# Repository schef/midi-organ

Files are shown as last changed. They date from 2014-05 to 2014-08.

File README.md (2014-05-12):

midi-organ
==========

Modifying and rebuilding electronics for an old electronic organ using GNU/Linux, Arduino, GEDA suite...

LICENSE:
Released under the Creative Commons Attribution share-Alike 3.0 License
http://creativecommons.org/licenses/by-sa/3.0/

CREDITS:
1)Symbols and footprints:
		-gedasymbols (www.gedasymbols.org)	
		-74HC165-1.sym symbol from https://github.com/thefekete/etc-geda/tree/master/lib/symbols/7400
2)Jordan, (http://dduino.blogspot.com/2012/04/arduino-74hc165-psio-shift-regsiter.html) - providing guide for Arduino 74HC165 PSIO Shift Regsiters

REFERENCES:
http://dduino.blogspot.com/2012/04/arduino-74hc165-psio-shift-regsiter.html
http://www.gedasymbols.org

Stjepan & Benjamin Horvat
http://horvat-elektronika.hr

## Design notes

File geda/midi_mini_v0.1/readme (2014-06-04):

commands:

refdes_renum arduino_standalone_extended.sch 74hc165_x4.sch 74hc164.sch 74hc595_x6.sch midi_connector.sch expresion_pedal_1.sch expresion_pedal_2.sch expresion_pedal_3.sch analog_generic_1.sch analog_generic_2.sch analog_generic_3.sch

gsch2pcb projekt

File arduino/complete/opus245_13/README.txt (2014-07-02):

ova verzija je napravljena za male skrablove orgulje sto znaci:
samo 2x595 (4 manje)
dodan relay za paljenje orgulja na pin D7
dodan potenciometar na A0
slozen da se boot sekvenca gasi na ulazni midi ton ch5
pojacalo se pali i gasi na ch5,127

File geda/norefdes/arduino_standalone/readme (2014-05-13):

REFERENCE:
http://www.arduino.cc/en/Main/StandaloneAssembly
http://www.instructables.com/id/Adding-ICSP-header-to-your-ArduinoAVR-board/#step0
http://www.open-electronics.org/arduino-isp-in-system-programming-and-stand-alone-circuits/

PART_LIST:
http://arduino.cc/en/Main/StandalonePartList

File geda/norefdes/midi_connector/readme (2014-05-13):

REFERENCES:
http://arduino.cc/en/Tutorial/Midi?from=Tutorial.MIDI

PART_LIST:
resistor 220 ohm

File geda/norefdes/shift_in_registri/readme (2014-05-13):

REFERENCES:
 http://dduino.blogspot.com/2012/04/arduino-74hc165-psio-shift-regsiter.html

PART_LIST:
resistor 10 Kohm

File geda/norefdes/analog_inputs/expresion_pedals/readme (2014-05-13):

REFERENCES: 
http://arduino.cc/en/Tutorial/AnalogInput
http://lizarum.com/assignments/physical_computing/2011/arduino_102.html

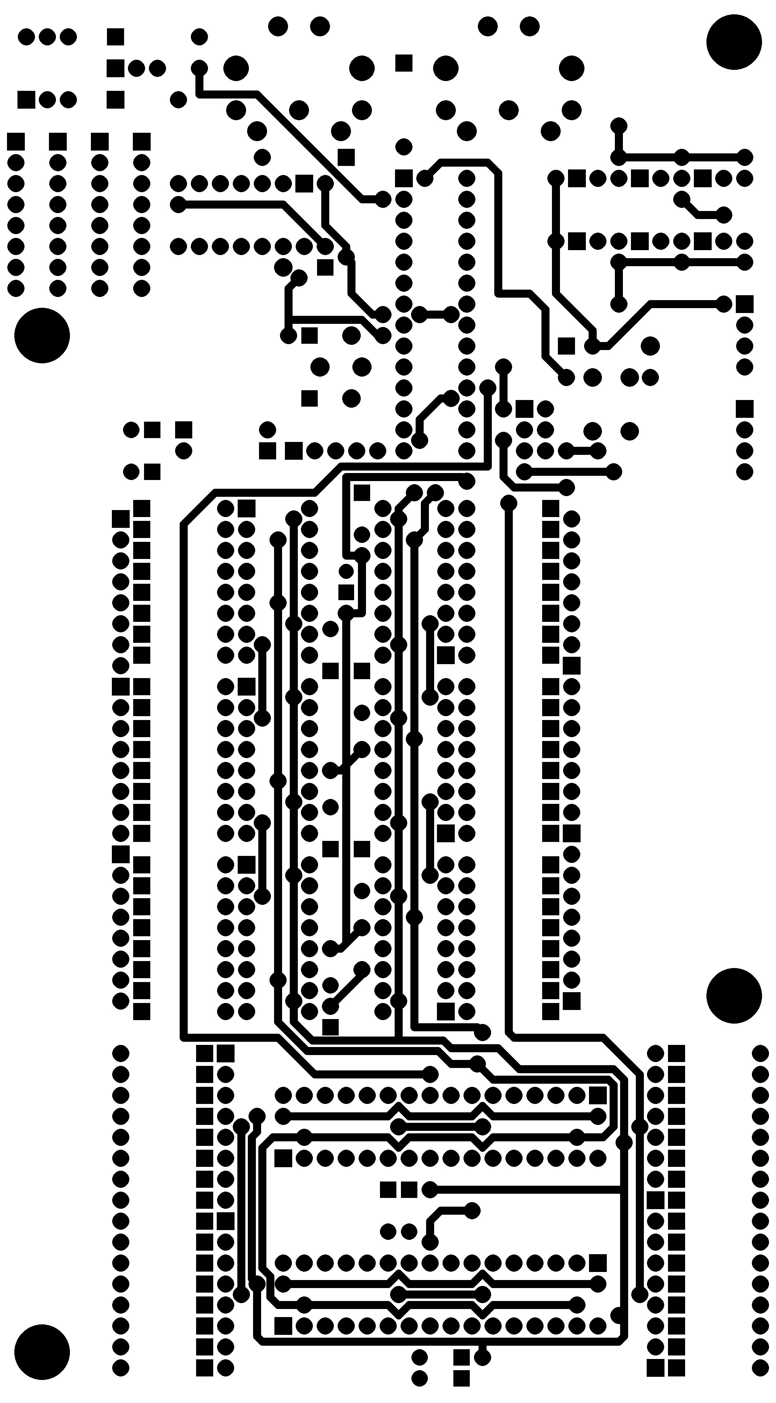
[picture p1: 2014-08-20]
geda/midi_mini_v0.1/midi_organ_v0.2.gcode.top.png

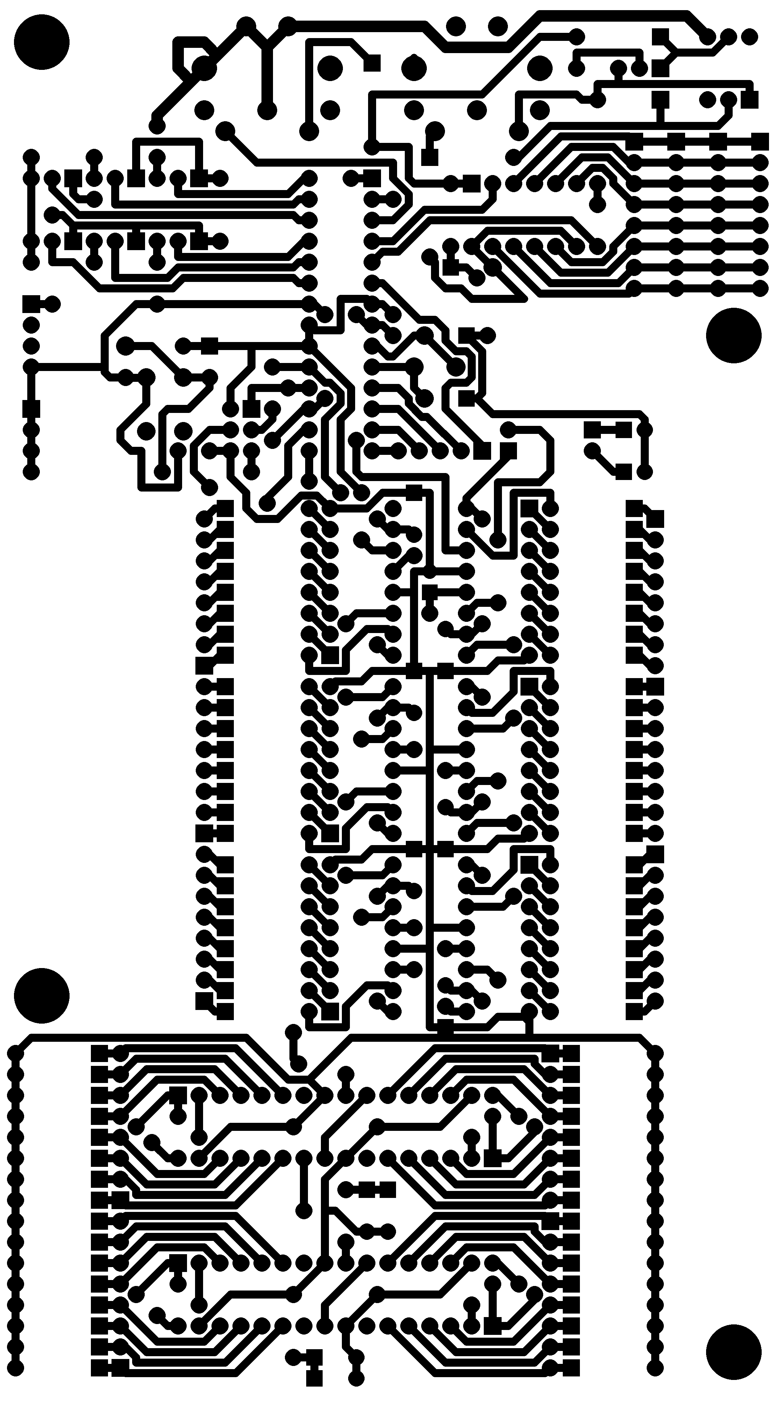
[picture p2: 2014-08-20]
geda/midi_mini_v0.1/midi_organ_v0.2.gcode.bottom.png

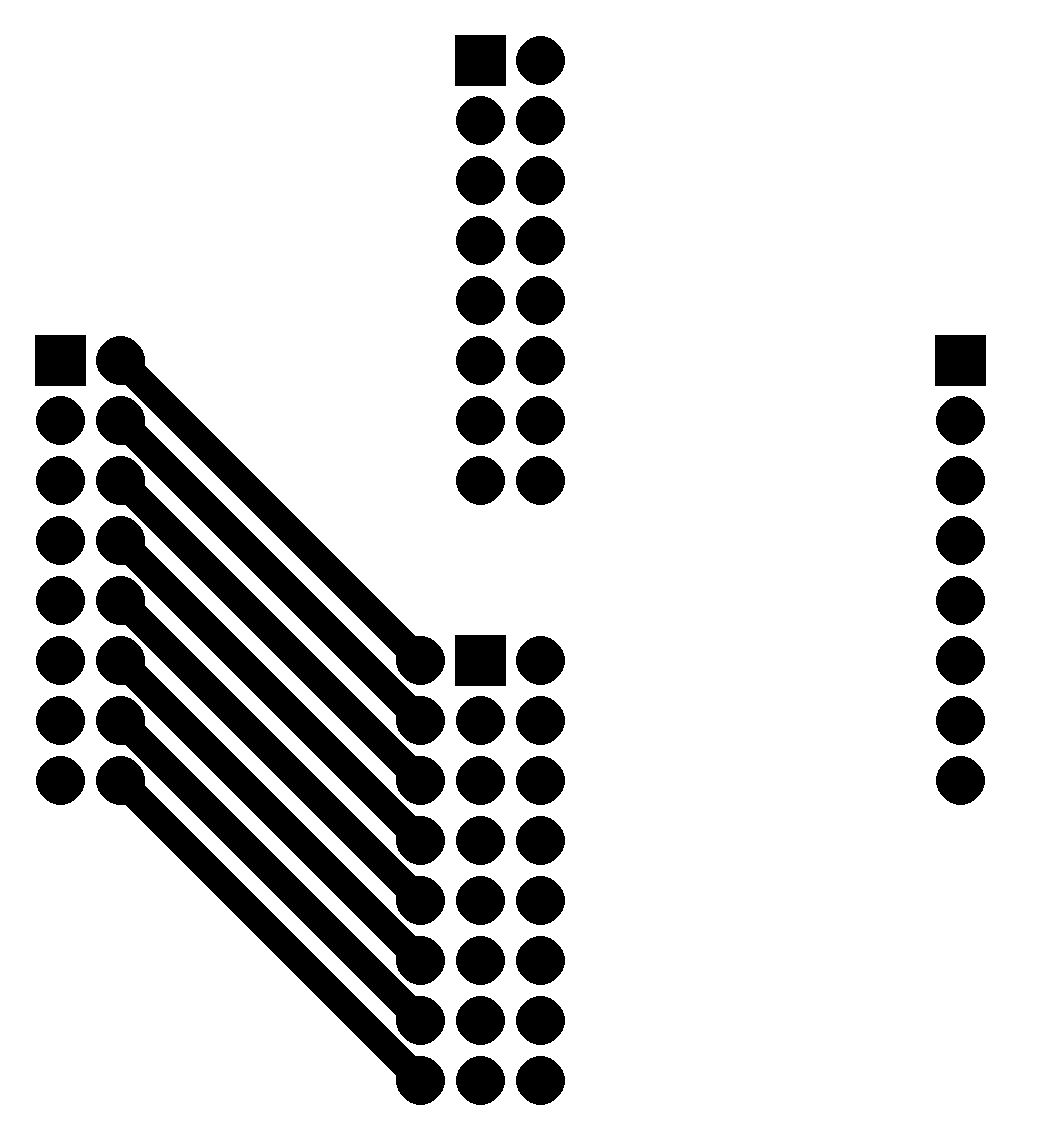
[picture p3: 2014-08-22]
geda/norefdes/fatar_converter/fatar_converter.gcode.top.png

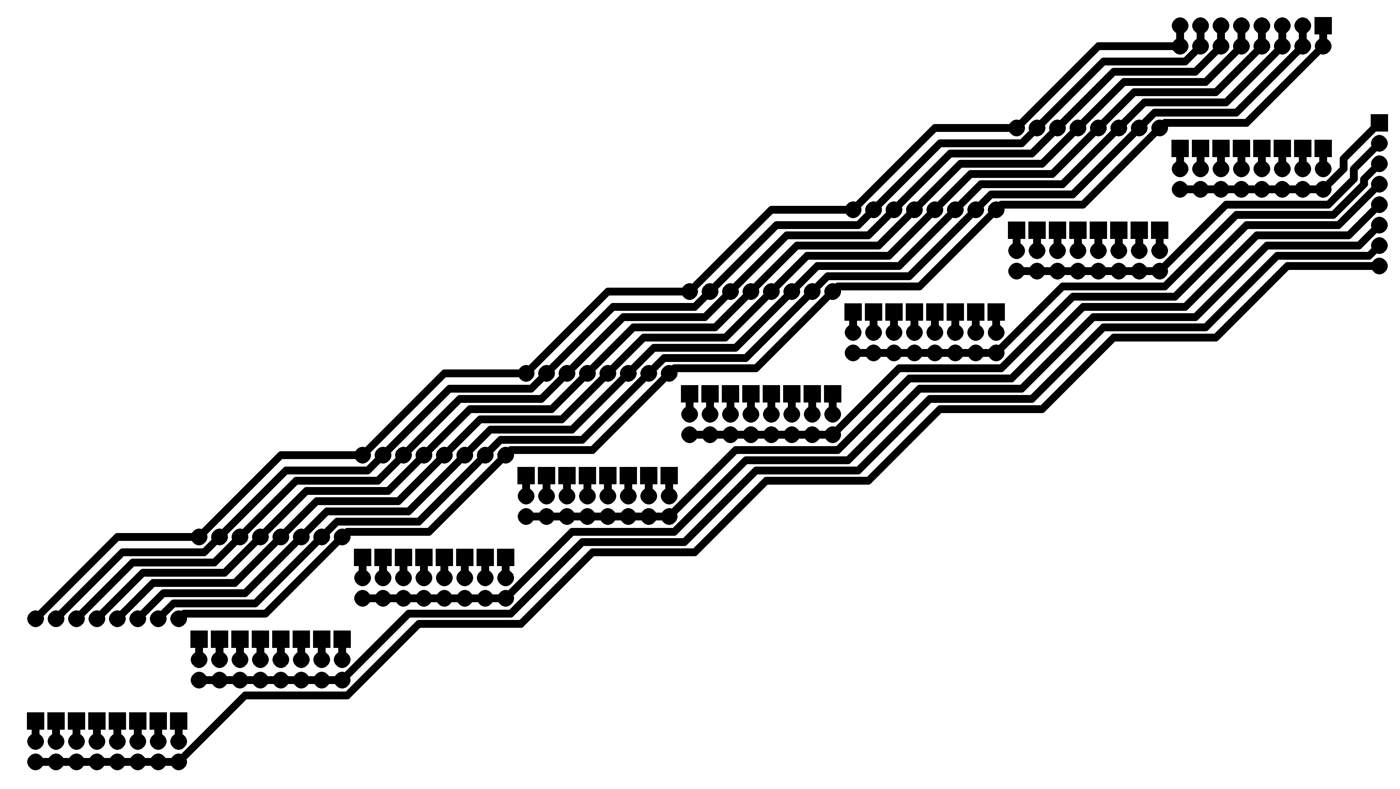
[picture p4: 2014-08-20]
geda/matrica/matrica.gcode.bottom.png

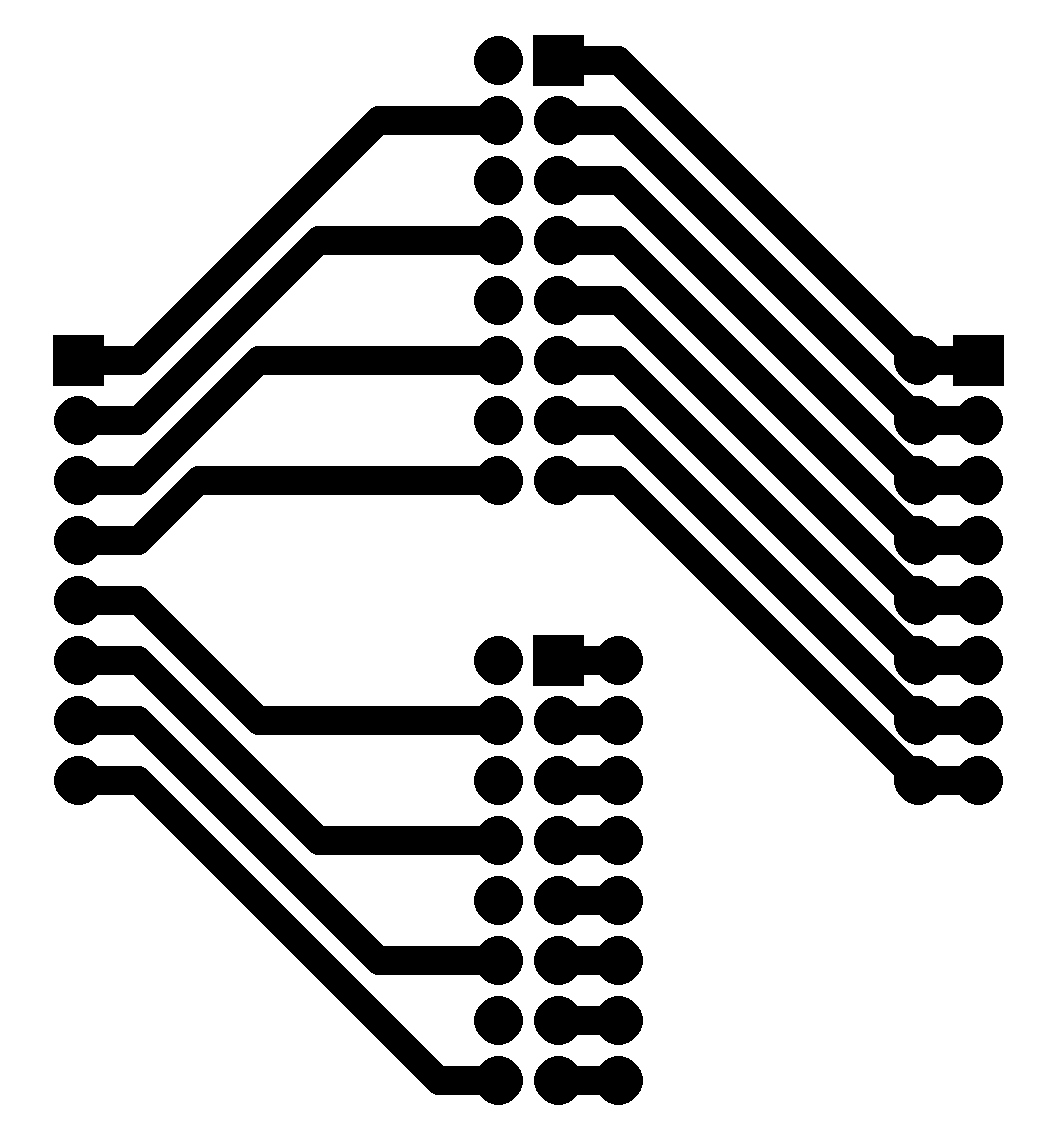
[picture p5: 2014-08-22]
geda/norefdes/fatar_converter/fatar_converter.gcode.bottom.png

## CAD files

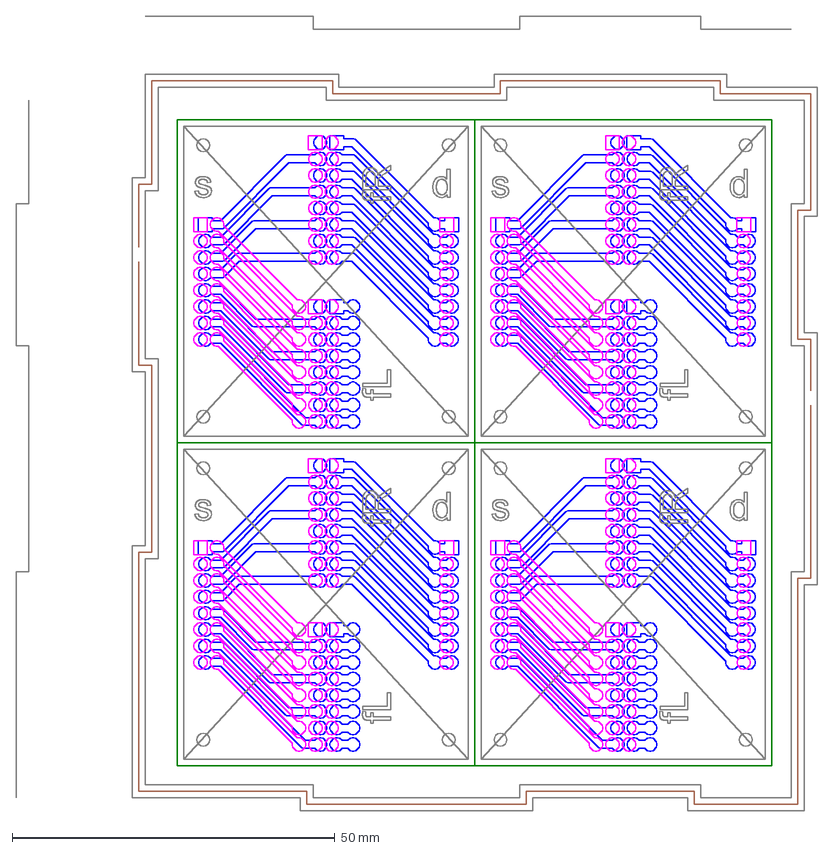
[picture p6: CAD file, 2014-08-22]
geda/norefdes/fatar_converter/fatar_converter.gcode.complete.dxf
124.0 x 123.0 mm

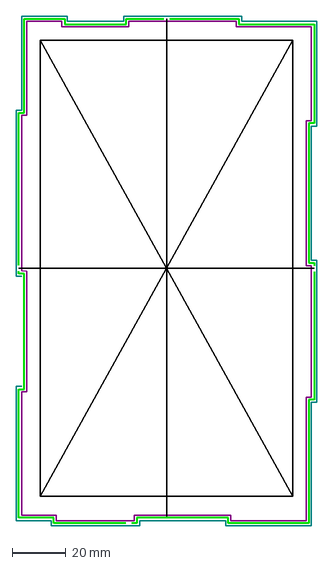
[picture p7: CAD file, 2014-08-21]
geda/midi_mini_v0.1/midi_organ_v0.2.gcode.complete.dxf
112.0 x 190.0 mm

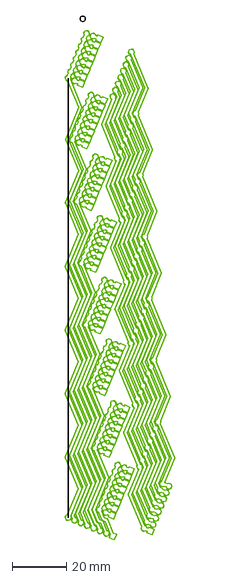
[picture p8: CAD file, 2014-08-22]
geda/matrica/matrica_deblje10mill.gcode-complete.dxf
40.2 x 192.4 mm

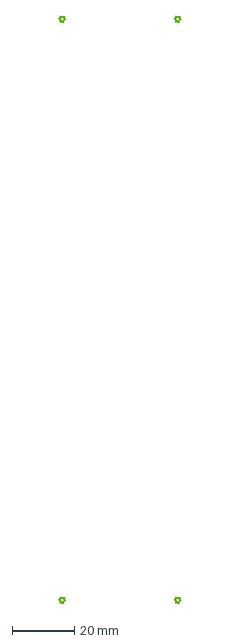
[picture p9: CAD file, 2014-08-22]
geda/matrica/matrica.gcode.complete[drill-3.25]-1mm.dxf
39.2 x 188.1 mm

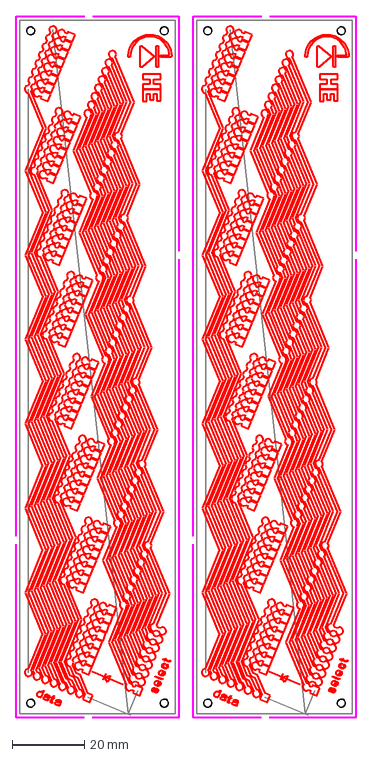
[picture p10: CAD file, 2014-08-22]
geda/matrica/matrica.gcode.complete-double.dxf
94.0 x 194.0 mm

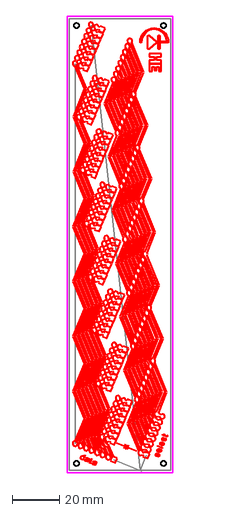
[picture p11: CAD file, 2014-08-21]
geda/matrica/matrica.gcode.complete.dxf
45.0 x 194.0 mm

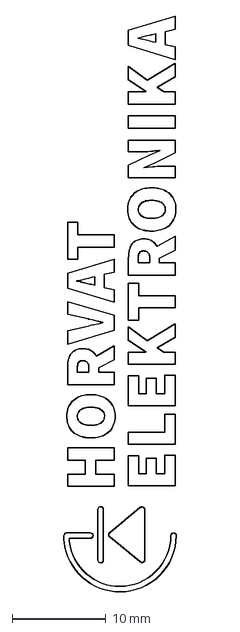
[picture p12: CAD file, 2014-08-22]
geda/midi_mini_v0.1/logo.dxf
12.0 x 61.4 mm

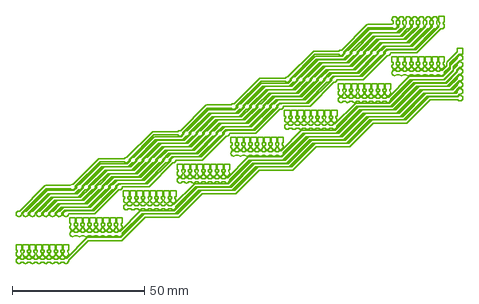
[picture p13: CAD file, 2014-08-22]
geda/matrica/matrica_deblje10mill.gcode.bottom.dxf
169.2 x 93.6 mm

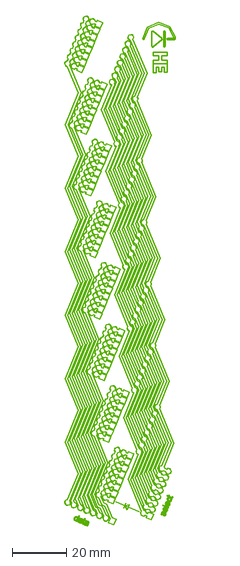
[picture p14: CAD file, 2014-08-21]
geda/matrica/matrica.gcode.bottom-06mm.dxf
40.6 x 187.5 mm

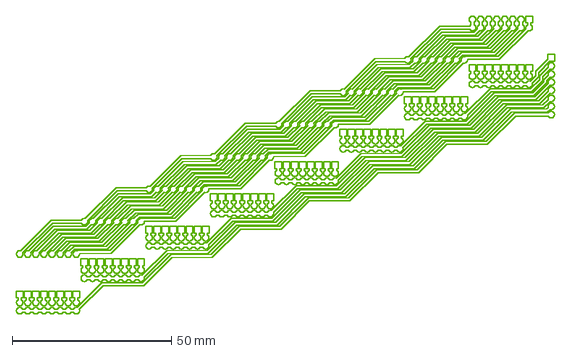
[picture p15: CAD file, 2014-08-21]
geda/matrica/matrica.gcode.bottom.dxf
169.2 x 93.6 mm

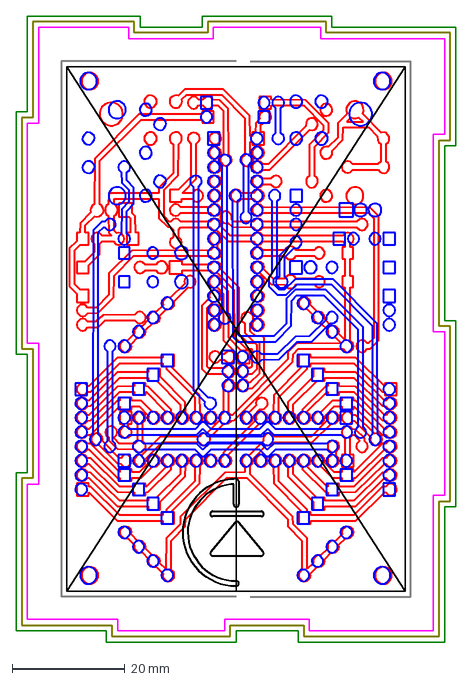
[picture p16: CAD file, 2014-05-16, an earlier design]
geda/complete_v0.1/complete.dxf
78.0 x 111.0 mm

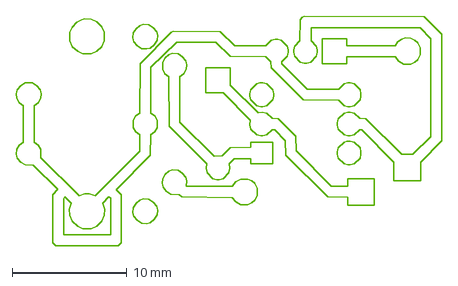
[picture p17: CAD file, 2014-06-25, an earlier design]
geda/complete_v0.2/midi_out_connector.gcode.bottom.dxf
37.1 x 20.0 mm

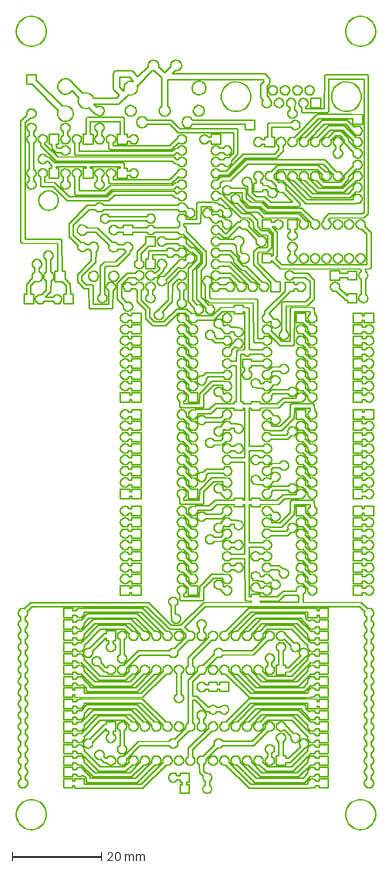
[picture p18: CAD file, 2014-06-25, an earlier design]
geda/complete_v0.2/midi_organ_v0.2_mm.gcode.bottom.dxf
80.4 x 182.0 mm

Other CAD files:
geda/matrica/matrica.gcode.complete.[drill-08].dxf
geda/matrica/matrica.gcode.complete.[drill-09].dxf
geda/matrica/matrica_deblje10mill.gcode.drill.dxf
geda/matrica/matrica.gcode.drill.dxf
geda/complete_v0.2/midi_out_connector.gcode.drill.dxf
geda/complete_v0.2/matrica_8x8.gcode.bottom.dxf
geda/complete_v0.2/matrica_8x8.gcode.bottom_multi.dxf
geda/complete_v0.2/midi_organ_v0.2.gcode.bottom.dxf
geda/complete_v0.2/midi_organ_v0.2.gcode.top.dxf
geda/complete_v0.2/midi_organ_v0.2_mm.gcode.all.[rub].dxf
geda/complete_v0.2/midi_organ_v0.2_mm.gcode.all.dxf
geda/complete_v0.2/midi_organ_v0.2_mm.gcode.top.dxf
geda/complete_v0.2/midi_out_connector.gcode.all.dxf

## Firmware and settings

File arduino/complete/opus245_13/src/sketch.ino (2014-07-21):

#include <MIDI.h>
//definiranje nozista

//164 pins
//int clearPin = 2; // enablepin
int data164Pin = 2;
int clock164Pin = 3;

//165 pins
//int inclearPin = 11; // enablepin
int data165Pin = 12;
int load165Pin = 10; // toggling this tells the 165 to read the value into its memory for reading

//595
int load595Pin = 9;
int data595Pin = 11;

//clock pin is shared between 165 and 595
int clockPin = 13;

byte commandByte;
byte noteByte;
byte velocityByte;

//int potPin = 0;
//int potVal = 0;
//int potOldVal = 0;
//int cc = 0;

int relay = 7;

int boot = 0;
int sekvencaOne[24] = {	B00000001, //24
			B00000010,
			B00000100,
			B00001000,
			B00010000,
			B00100000,
			B01000000,
			B10000000,
			B00000000,
			B00000000,
			B00000000,
			B00000000,
			B00000000,
			B00000000,
			B00000000,
			B00000000,
			B00000000,
			B10000000,
			B01000000,
			B00100000,
			B00010000,
			B00001000,
			B00000100,
			B00000010,
};

int sekvencaTwo[24] = {	B00000000, //24
			B00000000,
			B00000000,
			B00000000,
			B00000000,
			B00000000,
			B00000000,
			B00000000,
			B00000001,
			B00000010,
			B00000100,
			B00001000,
			B00010000,
			B00001000,
			B00000100,
		B00000010,
			B00000001,
			B00000000,
			B00000000,
			B00000000,
			B00000000,
			B00000000,
			B00000000,
			B00000000,
};
//inicializacija programa
void bootSequence(){
	do{
	//if(boot == 24)
	//  boot = 0;
  digitalWrite(load595Pin, LOW);
  //shiftOut(data595Pin, clockPin, MSBFIRST, sekvencaTwo[boot]);
  //shiftOut(data595Pin, clockPin, MSBFIRST, sekvencaOne[boot]);
  shiftOut(data595Pin, clockPin, MSBFIRST, boot);
  shiftOut(data595Pin, clockPin, MSBFIRST, boot);
  digitalWrite(load595Pin, HIGH);
  delay(100);
	if(MIDI.read()){
	//if (boot == 20){
    		//MIDI.setHandleNoteOn(noteon);
    		//MIDI.setHandleNoteOff(noteoff);
		break;
	}
boot++;
}
while(1);
  digitalWrite(load595Pin, LOW);
  shiftOut(data595Pin, clockPin, MSBFIRST, 0);
  shiftOut(data595Pin, clockPin, MSBFIRST, 0);
  digitalWrite(load595Pin, HIGH);
}

void setup() {

	//start serial
	//Serial.begin(9600);

	//164
	pinMode(data164Pin, OUTPUT);
	pinMode(clock164Pin, OUTPUT);  

	//165
	pinMode(data165Pin, INPUT);
	pinMode(load165Pin, OUTPUT);

	//595
	pinMode(load595Pin, OUTPUT);
	pinMode(data595Pin, OUTPUT);


	//shared pin
	pinMode(clockPin, OUTPUT);
  	pinMode(relay, OUTPUT);


  MIDI.begin(5);          // Launch MIDI and listen to channel 4
  //MIDI.turnThruOff();
bootSequence();
  //digitalWrite(relay, HIGH);
}

//definicija varijabla

//treba biti broj ulaza sa 165 u test primjeru 8 a u punoj funkciji 32
int readPin[32];

int buttonOne[64];
int oldButtonOne[64];
int buttonTwo[64];
int oldButtonTwo[64];
int buttonThree[64];
int oldButtonThree[64];
int buttonFour[64];
int oldButtonFour[64];

int ledStatus[64];
int oldLedStatus[64];

int midiLista[128];

int myByte = 0;
//byte noteOn = 144;
//byte noteOff = 128;

int ledLista[6];
int bitToByte[8] = {1, 2, 4, 8, 16, 32, 64, 128};

//definicija funkcija

void noteon(byte channel, byte note, byte velocity) {
  //if((channel == 5)&&(note == 127)){
  //  digitalWrite(relay, HIGH);
  //  }
  //else{
  midiLista[note] = 1;
  mojShift();
  //}
}

void noteoff(byte channel, byte note, byte velocity) {
  //if((channel == 5)&&(note == 127)){
  //  digitalWrite(relay, LOW);
  //  }
  //else{
  midiLista[note] = 0;
  mojShift();
  //}
}

void serialPrint(int key, int i, int stanje){ 
	Serial.print("k");
	Serial.print(key);
	Serial.print("-");
	Serial.print(i);
	Serial.print(":");
	Serial.print(stanje);
	Serial.println(""); 
}


void mojShift(){
  //bajt 1
  myByte = 0;
  for (int i = 0; i < 8; i++){
    myByte += (midiLista[(i+36)] * bitToByte[i]);
  }
  ledLista[0] = myByte;
//  //Serial.println(ledLista[0]);
//
  //bajt 2
  myByte = 0;
  for (int i = 0; i < 8; i++){
    myByte += (midiLista[(i+8+36)] * bitToByte[i]);
  }
  ledLista[1] = myByte;
//  //Serial.println(ledLista[1]);
//  //bajt 3
//  myByte = 0;
//  for (int i = 0; i < 8; i++){
//    myByte += (midiLista[(i+16+36)] * bitToByte[i]);
//  }
//  ledLista[2] = myByte;
//  //Serial.println(ledLista[2]);
//  //bajt 4
//  myByte = 0;
//  for (int i = 0; i < 8; i++){
//    myByte += (midiLista[(i+24+36)] * bitToByte[i]);
//  }
//  ledLista[3] = myByte;
//  //Serial.println(ledLista[3]);
//  //bajt 5
//  myByte = 0;
//  for (int i = 0; i < 8; i++){
//    myByte += (midiLista[(i+32+36)] * bitToByte[i]);
//  }
//  ledLista[4] = myByte;
//  //Serial.println(ledLista[4]);
//  //bajt 6
//  myByte = 0;
//  for (int i = 0; i < 8; i++){
//    myByte += (midiLista[(i+40+36)] * bitToByte[i]);
//  }
//  ledLista[5] = myByte;
  //Serial.println(ledLista[5]);

  //Serial.println("");
  //Serial.print(myByte);
  //Serial.println("");
  //Serial.println(ledLista[0]);
  //ledLista[0] = ;
  digitalWrite(load595Pin, LOW);
  //shiftOut(data595Pin, clockPin, MSBFIRST, ledLista[5]);
  //shiftOut(data595Pin, clockPin, MSBFIRST, ledLista[4]);
  //shiftOut(data595Pin, clockPin, MSBFIRST, ledLista[3]);
  //shiftOut(data595Pin, clockPin, MSBFIRST, ledLista[2]);
  shiftOut(data595Pin, clockPin, MSBFIRST, ledLista[1]);
  shiftOut(data595Pin, clockPin, MSBFIRST, ledLista[0]);
  digitalWrite(load595Pin, HIGH);
  //kraj ledica
  //Serial.println("--------");
  //delay(300);
}

int firstTime=0;

void loop() {
	//idemo 164 pin po pin od 1-8
	for(int j = 0; j < 8; ++j) //for 0 - 7 do
	{
		shiftOut(data164Pin, clock164Pin, MSBFIRST, 1 << j); // bit shift a logic high (1) value by i

		//shiftIn
		digitalWrite(load165Pin, 0); // read into register (tells the 165 to take a snapshot of its input pins)
		digitalWrite(load165Pin, 1); // done reading into register, ready for us to read    
		//Serial.print(j);
		//Serial.print(":");

		//za svaki pin od 164 citamo 32 pina sa 165(1-4)
		for(int i=0; i<32; i++){ // read each of the 165's 8 inputs (or its snapshot of it rather)
			// tell the 165 to send the inputs pin state
			digitalWrite(clockPin, 0);
			//tu je broj i-1
			readPin[(31-i)] = digitalRead(data165Pin); // read the state
			//Serial.print(readPin[(31-i)]);
			digitalWrite(clockPin, 1);
			//Serial.print (readPin[i]);
		}

		//---====ovde krece konvertiranje readPinova u klavijature jos nema sviranja----====//
		//klavijatura 1
		for (int i=0; i<8; i++){
			//this is my logic of Select and Data order -> C1=S1D1, C#1=S1D2
			//button[(j*8+i)] = readPin[i];
			//this if FATAR logic of Select and Data order C1=S1D1, C#1=S2D1
			buttonOne[(j+i*8)] = readPin[i];
		}
//		//klavijatura 2
		for (int i=8; i<16; i++){
			//this is my logic of Select and Data order -> C1=S1D1, C#1=S1D2
			//button[(j*8+i)] = readPin[i];
			//this if FATAR logic of Select and Data order C1=S1D1, C#1=S2D1
			//pazi na formulu
			buttonTwo[(j*8+(i-8))] = readPin[i];
		}
		//klavijatura 3
		for (int i=16; i<24; i++){
			//this is my logic of Select and Data order -> C1=S1D1, C#1=S1D2
			//button[(j*8+i)] = readPin[i];
			//this if FATAR logic of Select and Data order C1=S1D1, C#1=S2D1
			buttonThree[(j*8+(i-16))] = readPin[i];
		}
		//klavijatura 4
		for (int i=24; i<32; i++){
			//this is my logic of Select and Data order -> C1=S1D1, C#1=S1D2
			//button[(j*8+i)] = readPin[i];
			//this if FATAR logic of Select and Data order C1=S1D1, C#1=S2D1
			buttonFour[(j+(i-24)*8)] = readPin[i];
		}


		//ovde se citaju liste klavijatura pa se svira
		for (int i = 0; i < 64; i++){
			//klavijatura 1
			if (buttonOne[i] == 1){
				if (buttonOne[i] != oldButtonOne[i]){
                                        MIDI.sendNoteOn(i+36,100,1);
					//serialPrint(1, i, 1);
					//    noteOn(0x90, note, 0x45);
					oldButtonOne[i] = buttonOne[i];
				}
			}
			else {
				if (buttonOne[i] != oldButtonOne[i]){
                                        MIDI.sendNoteOff(i+36,0,1);
					//serialPrint(1, i, 0);
					//    noteOn(0x90, note, 0x00);
					oldButtonOne[i] = buttonOne[i];
				}

			}
			//klavijatura 2
			if (buttonTwo[i] == 1){
				if (buttonTwo[i] != oldButtonTwo[i]){
					//serialPrint(2, i, 1);
                                        MIDI.sendNoteOn(i+36,100,2);
					//    noteOn(0x90, note, 0x45);
					oldButtonTwo[i] = buttonTwo[i];
				}
			}
			else {
				if (buttonTwo[i] != oldButtonTwo[i]){
                                        MIDI.sendNoteOff(i+36,0,2);
					//serialPrint(2, i, 0);
					//    noteOn(0x90, note, 0x00);
					oldButtonTwo[i] = buttonTwo[i];
				}

			}
			//klavijatura 3
			if (buttonThree[i] == 1){
				if (buttonThree[i] != oldButtonThree[i]){
                                        MIDI.sendNoteOn(i+36,100,3);
					//serialPrint(3, i, 1);
					//    noteOn(0x90, note, 0x45);
					oldButtonThree[i] = buttonThree[i];
				}
			}
			else {
				if (buttonThree[i] != oldButtonThree[i]){
                                        MIDI.sendNoteOff(i+36,0,3);
					//serialPrint(3, i, 0);
					//    noteOn(0x90, note, 0x00);
					oldButtonThree[i] = buttonThree[i];
				}

			}
			//klavijatura 4
			if (buttonFour[i] == 1){
				if (buttonFour[i] != oldButtonFour[i]){
                                        MIDI.sendNoteOn(i+36,100,4);
					//serialPrint(4, i, 1);
					//    noteOn(0x90, note, 0x45);
					oldButtonFour[i] = buttonFour[i];
				}
			}
			else {
				if (buttonFour[i] != oldButtonFour[i]){
                                        MIDI.sendNoteOff(i+36,0,4);
					//serialPrint(4, i, 0);
					//    noteOn(0x90, note, 0x00);
					oldButtonFour[i] = buttonFour[i];
				}

			}
		}


		//potenciometar za zelozinjei (swell)
		//potVal = analogRead(potPin);
		//if (potVal != potOldVal){
		//	cc = potVal/8;
		//	MIDI.sendControlChange(16,cc,1);
		//	potOldVal = potVal;
		//}

		//tu pocinje citanje midi informacija za ledice
		//u ovom slucaju pretpostavimo da koristimo buttonOne umjesto midiListe

		//tu se konvertira midi ulazni pa se smjesta u listu i odma shifta
		//pass


	}
  if (MIDI.read())                // If we have received a message
  {
    //digitalWrite(LED,HIGH);
    //MIDI.sendNoteOn(42,127,1);  // Send a Note (pitch 42, velo 127 on channel 1)
    //delay(1000);		        // Wait for a second
    //MIDI.sendNoteOff(42,0,1);   // Stop the note
    //digitalWrite(LED,LOW);
    MIDI.setHandleNoteOn(noteon);                             // call noteon when a note on message is received
    MIDI.setHandleNoteOff(noteoff);                            // call noteoff when a note off message is received
  }
	//kraj petlje 164
}

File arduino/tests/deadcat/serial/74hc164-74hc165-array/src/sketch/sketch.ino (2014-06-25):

//164 pins
//int clearPin = 2; // enablepin
int dataPin = 2;
int clockPin = 3;

//165 pins
//int inclearPin = 11; // enablepin
int indataPin = 12;
int inclockPin = 13;
int inloadPin = 10; // toggling this tells the 165 to read the value into its memory for reading

void setup() {

	//start serial
	Serial.begin(9600);

	//164
	pinMode(dataPin, OUTPUT);
	pinMode(clockPin, OUTPUT);  

	//165
	pinMode(indataPin, INPUT);
	pinMode(inclockPin, OUTPUT);  
	pinMode(inloadPin, OUTPUT);
}

int readPin[8];
int button[64];
int oldButton[64];

void loop() {
	for(int j = 0; j < 8; ++j) //for 0 - 7 do
	{
		shiftOut(dataPin, clockPin, MSBFIRST, 1 << j); // bit shift a logic high (1) value by i

		//shiftIn
		digitalWrite(inloadPin, 0); // read into register (tells the 165 to take a snapshot of its input pins)
		digitalWrite(inloadPin, 1); // done reading into register, ready for us to read    
		//Serial.print(j);
		//Serial.print(":");
		for(int i=0; i<8; i++){ // read each of the 165's 8 inputs (or its snapshot of it rather)
			// tell the 165 to send the inputs pin state
			digitalWrite(inclockPin, 0);
			readPin[(7-i)] = digitalRead(indataPin); // read the state
			digitalWrite(inclockPin, 1);
			//Serial.print (readPin[i]);
		}

		for (int i=0; i<8; i++){
			//this is my logic of Select and Data order -> C1=S1D1, C#1=S1D2
			//button[(j*8+i)] = readPin[i];
			//this if FATAR logic of Select and Data order C1=S1D1, C#1=S2D1
			button[(j*8+i)] = readPin[i];
		}

		for (int i = 0; i < 64; i++){
			if (button[i] == 1){
				if (button[i] != oldButton[i]){
					Serial.print(i);
					Serial.print(":1");
					Serial.println(""); 
					oldButton[i] = button[i];
				}
			}
			else {
				if (button[i] != oldButton[i]){
					Serial.print(i);
					Serial.print(":0");
					Serial.println(""); 
					oldButton[i] = button[i];
				}

			}
		}

		//delay(2000);
	}

}

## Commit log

2014-05-12 dodani sch fileovi za shift registre x2 i x3 & dodani 74HC165-1.sym u usr_lib/
    [shift_registri_x2_norefnum.sch, shift_registri_x3_norefnum.sch]
2014-05-13 doraden arduino i dodan readme | dodan midi connector i readme | doradeni shift registri i dodan readme | dodani symbole za midi i jumper | dodana volume pedala i readme
    [arduino_standalone_extended_norefnum.sch, arduino_standalone_norefnum.sch, midi_connector_norefnum.sch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]
2014-05-14 modified arduino_standalone
    [arduino_standalone_extended_norefnum.sch, arduino_standalone_norefnum.sch]
2014-05-14 modified midi_conector, shift_registri, volume_pedal
    [midi_connector_norefnum.sch, shift_registri_x2_norefnum.sch, shift_registri_x3_norefnum.sch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]
2014-05-14 dodani footprintovi za midi, reset switch i crystal
2014-05-15 modified arduino_standalone_extended i midi_connector
    [arduino_standalone_extended_norefnum.sch, midi_connector_norefnum.sch]
2014-05-15 dodani folder complete
    [arduino_standalone_extended.sch, midi_connector.sch, shift_registri_x2.sch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]
2014-05-16 generated gcode
    [complete.dxf]
2014-05-21 added symbols and footprints
2014-05-21 fixed bugs and added serial connector, power led, power input connector
    [arduino_standalone_extended_norefnum.sch, arduino_standalone_norefnum.sch]
2014-05-21 promjenjena symbol diode i izbrisani krivi
    [arduino_standalone_extended_norefnum.sch]
2014-05-21 isto promijenjen symbol diode
    [arduino_standalone_norefnum.sch]
2014-05-26 dodani folder analog inputs i elementi
    [analog_generic_norefnum_1.sch, analog_generic_norefnum_2.sch, analog_generic_norefnum_3.sch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]
2014-05-26 dodani folder complete_v0.2 sa fileovima
    [74hc164.sch, 74hc165_x4.sch, 74hc595_x6.sch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]
2014-05-26 dodani folderi shift in i out, dodani shift registri 74hc164 i 74hc595
    [74hc164_norefnum.sch, 74hc165_x2_norefnum.sch, 74hc165_x3_norefnum.sch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]
2014-05-26 zamijenjeni folder complete u complete_v0.1
    [arduino_standalone_extended_norefnum.sch, complete.dxf, midi_connector.sch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]
2014-05-26 izbrisani folder complete
    [arduino_standalone_extended.sch, complete.dxf, midi_connector.sch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]
2014-05-26 izbrisani folder shift_registri i volume_pedal
    [shift_registri_x2_norefnum.sch, shift_registri_x3_norefnum.sch, volume_pedal_norefnum.sch]
2014-05-26 promijenjeni arduino_extended i izbrisani symbol 74HC165-1.sym
    [arduino_standalone_extended_norefnum.sch]
2014-05-26 popravljeni fileovi u complete_v0.2 i dodani symbol header-1x3.sym
    [74hc164.sch, 74hc165_x4.sch, 74hc595_x6.sch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]
2014-05-26 modified complete_v0.2 and midi_connector
    [74hc164.sch, 74hc165_x4.sch, 74hc595_x6.sch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]
2014-06-04 fixed pin numbers
2014-06-04 complete test for arduino
2014-06-04 added pcb for complete organ
    [74hc164.sch, 74hc165_x4.sch, analog_generic_1.sch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]
2014-06-04 dodani pcb za matricu 8x8 i gcode
2014-06-04 ready for cnc
    [midi_organ_v0.2_mm.gcode.all.dxf]
2014-06-05 midi out connector
    [midi_out_connector.sch]
2014-06-25 prebaceno sve u folder norefdes
    [74hc164.sch, 74hc165_x2.sch, 74hc165_x3.sch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]
2014-06-25 arduino tests
2014-06-25 geda commit
    [matrica_8x8.gcode.bottom.dxf, matrica_8x8.gcode.bottom_multi.dxf, midi_in.sch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]
2014-08-20 dodani complete_v0.3 i .sch fileovi
    [74hc164.sch, 74hc164_x4.sch, 74hc165_x4.sch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]
2014-08-21 0.8mm mirror
2014-08-21 09mm mirror
2014-08-21 ispravljen za v2
    [midi_organ_v0.2.gcode.complete.dxf]
2014-08-21 matrika gcode
    [matrica.gcode.bottom.dxf, matrica.gcode.complete.dxf, matrica.gcode.drill.dxf]
2014-08-21 novi bottom
    [matrica.gcode.bottom-06mm.dxf, matrica.gcode.complete.dxf]
2014-08-21 deblje linije matrika
    [logo.dxf, matrica.gcode.complete-double.dxf, matrica.gcode.complete.[drill-08].dxf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]
2014-08-22 fatar connector i symboli za header14
    [fatar_converter.sch, fatar_converter_norefdes.sch]
2014-10-06 dodano sve i svasta :)
    [74hc164_x4.sch, 74hc165_x4.sch, 74hc595_x6.sch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]
2014-10-06 clean baby
    [midi_in_connector.sch]
